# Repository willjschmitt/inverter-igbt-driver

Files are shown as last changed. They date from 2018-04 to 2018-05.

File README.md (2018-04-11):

# inverter-igbt-driver
IGBT driver for Electric Vehicle Inverter

This project is a work in progress to design a simple IGBT driver for use with the controls designed in https://github.com/willjschmitt/electric-vehicle-controller.

Board is designed in [KiCad](http://kicad-pcb.org/).

## Getting Started
```
git clone https://github.com/willjschmitt/inverter-igbt-driver
```

Install KiCad. Open up the KiCad project!

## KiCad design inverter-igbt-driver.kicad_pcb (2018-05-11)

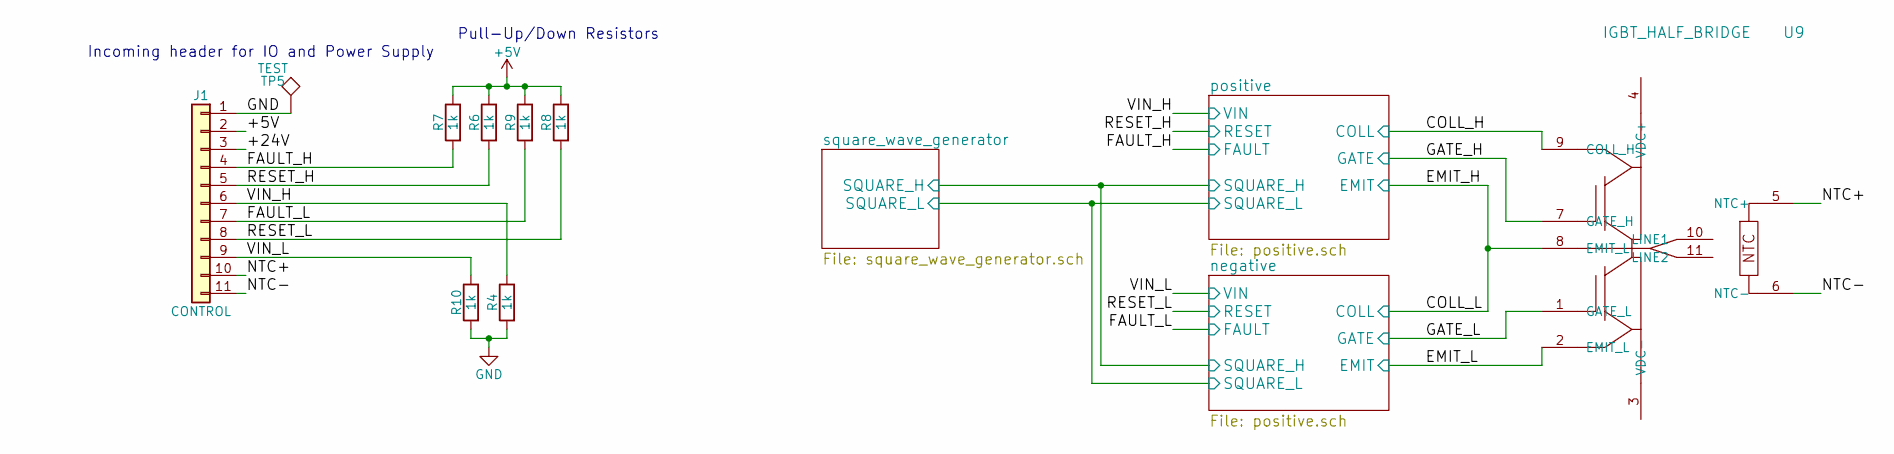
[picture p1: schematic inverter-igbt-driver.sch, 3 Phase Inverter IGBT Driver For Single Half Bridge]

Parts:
J1: CONTROL; Pin_Header_Straight_1x11_Pitch2.54mm
R4, R6, R7, R8, R9, R10: 1k; R_0402
TP5: TEST; TP RCT (0805)
U9: IGBT_HALF_BRIDGE; MG06600WB-BN4MM

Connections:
+5V: J1.2, R6.1, R7.1, R8.1, R9.1; also elsewhere on the board
+24V: J1.3; also elsewhere on the board
/COLL_H: U9.9 (COLL_H); also elsewhere on the board
/COLL_L: U9.8 (EMIT_L); also elsewhere on the board
/EMIT_L: U9.2 (EMIT_L); also elsewhere on the board
/FAULT_H: J1.4, R7.2; also elsewhere on the board
/FAULT_L: J1.7, R9.2; also elsewhere on the board
/GATE_H: U9.7 (GATE_H); also elsewhere on the board
/GATE_L: U9.1 (GATE_L); also elsewhere on the board
/NTC+: J1.10, U9.5 (NTC+)
/NTC-: J1.11, U9.6 (NTC-)
/RESET_H: J1.5, R6.2; also elsewhere on the board
/RESET_L: J1.8, R8.2; also elsewhere on the board
/VIN_H: J1.6, R4.1; also elsewhere on the board
/VIN_L: J1.9, R10.1; also elsewhere on the board
GND: J1.1, R4.2, R10.2, TP5.1; also elsewhere on the board

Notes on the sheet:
Incoming header for IO and Power Supply
Pull-Up/Down Resistors

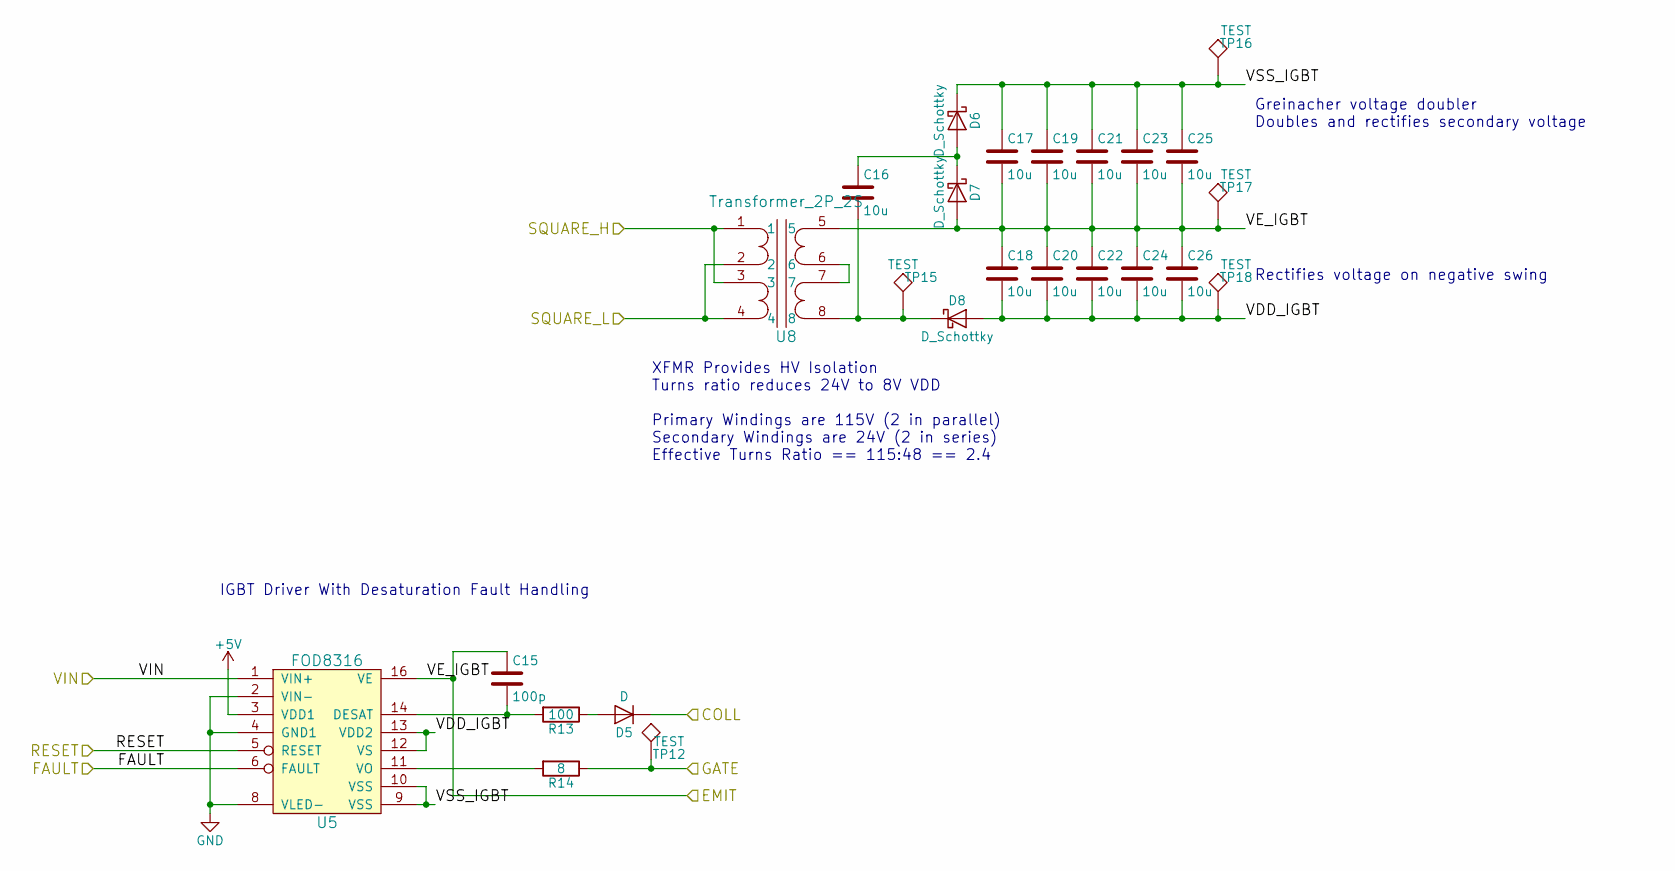
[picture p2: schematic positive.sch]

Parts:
C2, C3, C4, C5, C6, C7, C8, C9, C10, C11, C12: 10u; C_1206_HandSoldering
C13: 100p; C_1206_HandSoldering
D1, D2, D3: D_Schottky; D_SOD-123F
D4: D; DO-214AC
R2: 100; R_1206_HandSoldering
R3: 8; R_Axial_DIN0207_L6.3mm_D2.5mm_P7.62mm_Horizontal
TP4, TP6, TP7, TP8, TP9: TEST; TP RCT (0805)
U3: FOD8316; SOIC-16W_7.5x10.3mm_Pitch1.27mm
U6: Transformer_2P_2S; FS48-050-C2

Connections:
+5V: U3.3 (VDD1); also elsewhere on the board
/COLL_H: D4.1 (K); also elsewhere on the board
/COLL_L: C3.2, C4.1, C5.2, C6.1, C7.2, C8.1, C9.2, C10.1, C11.2, C12.1, C13.1, D2.2 (A), TP8.1, U3.16 (VE), U6.5; also elsewhere on the board
/FAULT_H: U3.6 (FAULT); also elsewhere on the board
/GATE_H: R3.1, TP4.1; also elsewhere on the board
/RESET_H: U3.5 (RESET); also elsewhere on the board
/VIN_H: U3.1 (VIN+); also elsewhere on the board
/negative/SQUARE_H: U6.1, U6.3; also elsewhere on the board
/negative/SQUARE_L: U6.2, U6.4; also elsewhere on the board
/positive/VDD_IGBT: C4.2, C6.2, C8.2, C10.2, C12.2, D3.2 (A), TP9.1, U3.12 (VS), U3.13 (VDD2)
/positive/VSS_IGBT: C3.1, C5.1, C7.1, C9.1, C11.1, D1.1 (K), TP7.1, U3.9 (VSS), U3.10 (VSS)
GND: U3.2 (VIN-), U3.4 (GND1), U3.8 (VLED-); also elsewhere on the board
unnamed: C2.1, D1.2 (A), D2.1 (K)
unnamed: C2.2, D3.1 (K), TP6.1, U6.8
unnamed: C13.2, R2.2, U3.14 (DESAT)
unnamed: D4.2 (A), R2.1
unnamed: R3.2, U3.11 (VO)
unnamed: U6.6, U6.7

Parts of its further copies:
C15: 100p; C_1206_HandSoldering
C16, C17, C18, C19, C20, C21, C22, C23, C24, C25, C26: 10u; C_1206_HandSoldering
D5: D; DO-214AC
D6, D7, D8: D_Schottky; D_SOD-123F
R13: 100; R_1206_HandSoldering
R14: 8; R_Axial_DIN0207_L6.3mm_D2.5mm_P7.62mm_Horizontal
TP12, TP15, TP16, TP17, TP18: TEST; TP RCT (0805)
U5: FOD8316; SOIC-16W_7.5x10.3mm_Pitch1.27mm
U8: Transformer_2P_2S; FS48-050-C2

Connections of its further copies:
+5V: U5.3 (VDD1); also elsewhere on the board
/COLL_L: D5.1 (K); also elsewhere on the board
/EMIT_L: C15.1, C17.2, C18.1, C19.2, C20.1, C21.2, C22.1, C23.2, C24.1, C25.2, C26.1, D7.2 (A), TP17.1, U5.16 (VE), U8.5; also elsewhere on the board
/FAULT_L: U5.6 (FAULT); also elsewhere on the board
/GATE_L: R14.1, TP12.1; also elsewhere on the board
/RESET_L: U5.5 (RESET); also elsewhere on the board
/VIN_L: U5.1 (VIN+); also elsewhere on the board
/negative/SQUARE_H: U8.1, U8.3; also elsewhere on the board
/negative/SQUARE_L: U8.2, U8.4; also elsewhere on the board
/negative/VDD_IGBT: C18.2, C20.2, C22.2, C24.2, C26.2, D8.2 (A), TP18.1, U5.12 (VS), U5.13 (VDD2)
/negative/VSS_IGBT: C17.1, C19.1, C21.1, C23.1, C25.1, D6.1 (K), TP16.1, U5.9 (VSS), U5.10 (VSS)
GND: U5.2 (VIN-), U5.4 (GND1), U5.8 (VLED-); also elsewhere on the board
unnamed: C15.2, R13.2, U5.14 (DESAT)
unnamed: C16.1, D6.2 (A), D7.1 (K)
unnamed: C16.2, D8.1 (K), TP15.1, U8.8
unnamed: D5.2 (A), R13.1
unnamed: R14.2, U5.11 (VO)
unnamed: U8.6, U8.7

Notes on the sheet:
XFMR Provides HV Isolation Turns ratio reduces 24V to 8V VDD Primary Windings are 115V (2 in parallel) Secondary Windings are 24V (2 in series) Effective Turns Ratio == 115:48 == 2.4
Greinacher voltage doubler Doubles and rectifies secondary voltage
Rectifies voltage on negative swing
IGBT Driver With Desaturation Fault Handling

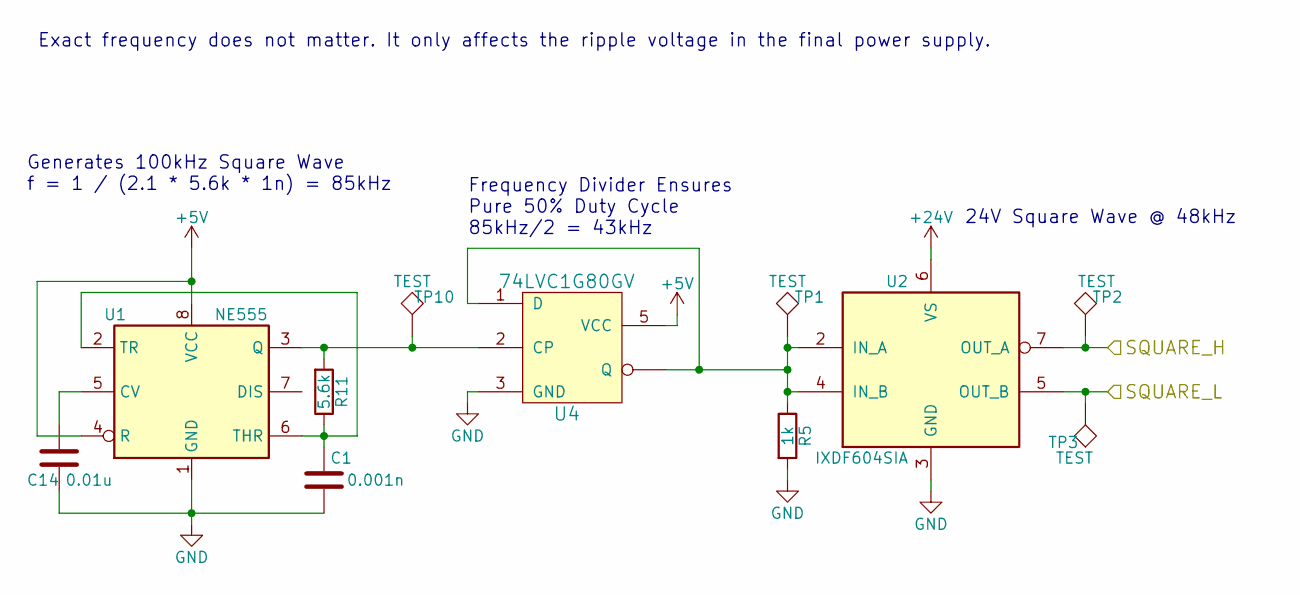
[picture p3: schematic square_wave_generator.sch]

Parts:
C1: 0.001n; C_0603_HandSoldering
C14: 0.01u; C_0603_HandSoldering
R5: 1k; R_0402
R11: 5.6k; R_0603_HandSoldering
TP1, TP2, TP3, TP10: TEST; TP RCT (0805)
U1: NE555; SOIC-8_3.9x4.9mm_Pitch1.27mm
U2: IXDF604SIA; SOIC-8_3.9x4.9mm_Pitch1.27mm
U4: 74LVC1G80GV; SOT-353_SC-70-5_Handsoldering

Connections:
+5V: U1.4 (R), U1.8 (VCC), U4.5 (VCC); also elsewhere on the board
+24V: U2.6 (VS); also elsewhere on the board
/negative/SQUARE_H: TP2.1, U2.7 (OUT_A); also elsewhere on the board
/negative/SQUARE_L: TP3.1, U2.5 (OUT_B); also elsewhere on the board
GND: C1.2, C14.2, R5.2, U1.1 (GND), U2.3 (GND), U4.3 (GND); also elsewhere on the board
unnamed: C1.1, R11.1, U1.2 (TR), U1.6 (THR)
unnamed: C14.1, U1.5 (CV)
unnamed: R5.1, TP1.1, U2.2 (IN_A), U2.4 (IN_B), U4.1 (D), U4.~ (Q)
unnamed: R11.2, TP10.1, U1.3 (Q), U4.2 (CP)

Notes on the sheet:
Generates 100kHz Square Wave f = 1 / (2.1 * 5.6k * 1n) = 85kHz
24V Square Wave @ 48kHz
Frequency Divider Ensures Pure 50% Duty Cycle 85kHz/2 = 43kHz
Exact frequency does not matter. It only affects the ripple voltage in the final power supply.

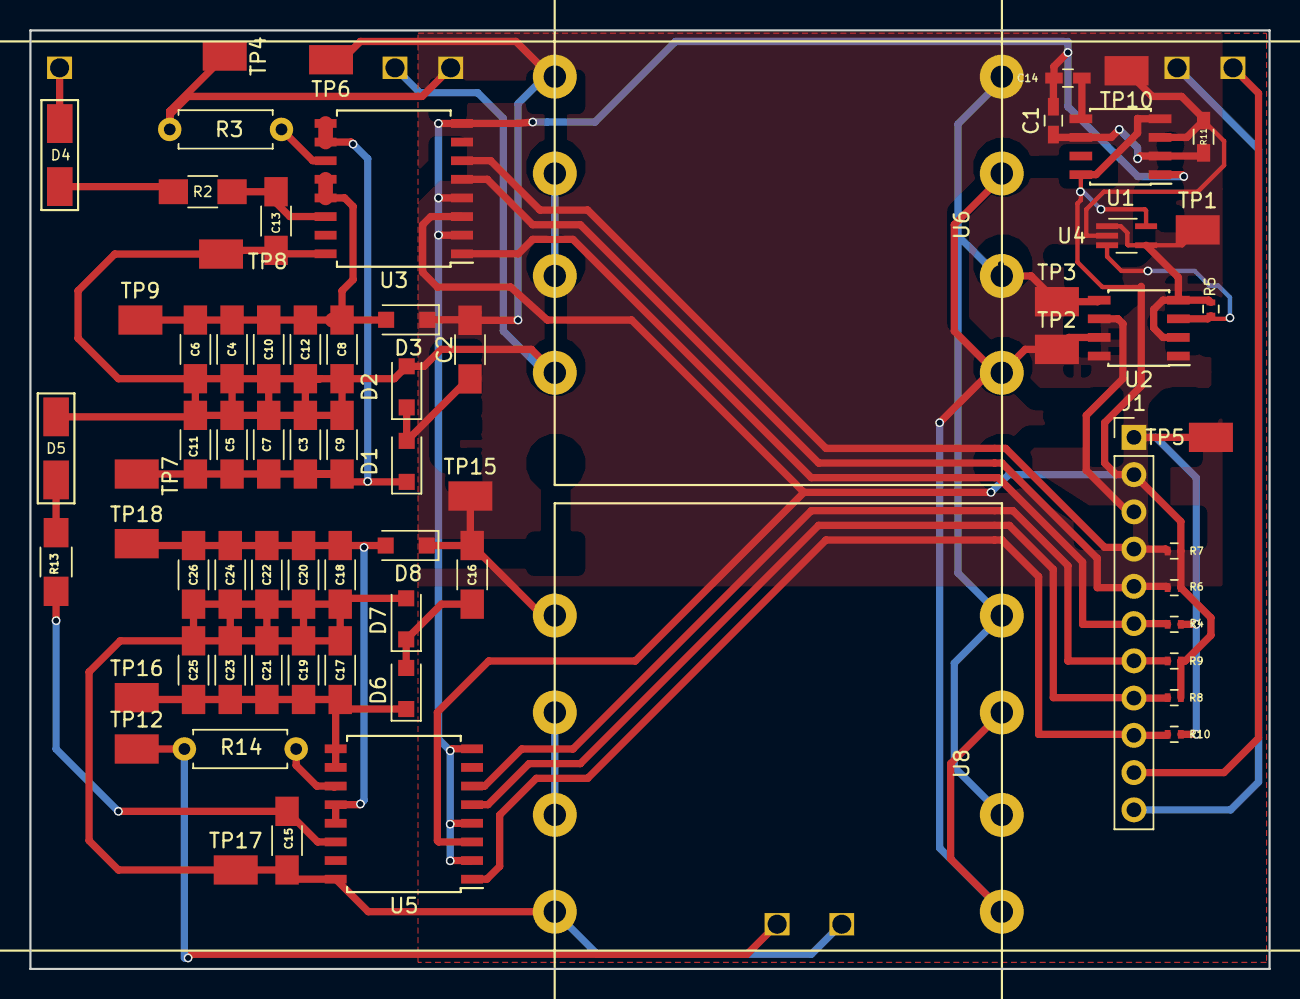
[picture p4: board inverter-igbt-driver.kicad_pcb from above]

Board: 2 copper layers, 84.5 x 64.0 mm, 70 parts (0 on the bottom side), 38 nets.

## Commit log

2018-04-10 First attempt at a complete IGBT driver.
    [inverter-igbt-driver.kicad_pcb, inverter-igbt-driver.sch]
2018-04-10 Adds pull-down resistors for logic nets.
    [inverter-igbt-driver.kicad_pcb, inverter-igbt-driver.sch]
2018-04-10 Add GND test point.
    [inverter-igbt-driver.kicad_pcb, inverter-igbt-driver.sch]
2018-04-10 Fix emitter connection.
    [inverter-igbt-driver.kicad_pcb]
2018-04-11 Switching pull-down to pull-up resistors for fault/reset.
    [inverter-igbt-driver.kicad_pcb, inverter-igbt-driver.sch]
2018-04-20 Refactor into schematic.
    [inverter-igbt-driver.kicad_pcb, inverter-igbt-driver.sch, positive.sch]
2018-04-20 Fix test point connection.
    [inverter-igbt-driver.kicad_pcb]
2018-04-21 Including both igbt drivers on one board.
    WIP
    [inverter-igbt-driver.kicad_pcb, inverter-igbt-driver.sch, positive.sch]
2018-04-21 Add _H suffix to hot leg.
    [inverter-igbt-driver.kicad_pcb, inverter-igbt-driver.sch]
2018-04-21 Move square wave generator to single module.
    [inverter-igbt-driver.kicad_pcb, inverter-igbt-driver.sch, positive.sch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]
2018-04-21 Fixing layout
    [inverter-igbt-driver.kicad_pcb, inverter-igbt-driver.sch]
2018-04-22 Completed layout with one connector.
    [inverter-igbt-driver.kicad_pcb, inverter-igbt-driver.sch, positive.sch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]
2018-04-29 Wire adjustments
    [inverter-igbt-driver.sch]
2018-05-05 Changed 555 timer configuration.
    555 timer was not behaving correctly. Added resistor to out for timing and increased resistor to 5V to mostly open circuit (in steady state).
    Added extra coupling capacitor for control voltage.
    [inverter-igbt-driver.kicad_pcb, positive.sch, square_wave_generator.sch]
2018-05-05 Adds NTC to connector.
    Completes 555 rewire.
    Rewires IGBT signals to layout more simply.
    [inverter-igbt-driver.kicad_pcb, inverter-igbt-driver.sch, positive.sch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]
2018-05-05 Fix hole size for avoiding slotting in OshPark drilling.
    [inverter-igbt-driver.kicad_pcb]
2018-05-05 Cleaning up layout of main connector.
    [inverter-igbt-driver.sch]
2018-05-08 Changing 555 timer again to remove pullup resistor and discharge.
    [inverter-igbt-driver.kicad_pcb, square_wave_generator.sch]
2018-05-08 Adding d-flop to achieve 50% duty cycle
    555 timer config cannot guarantee 50% duty cycle, but a frequency divider can.
    [inverter-igbt-driver.kicad_pcb, inverter-igbt-driver.sch, square_wave_generator.sch]
2018-05-11 Adjust resistor value and cap values for pulse generator
    [inverter-igbt-driver.sch, positive.sch, square_wave_generator.sch]
2018-05-11 Update values.
    [inverter-igbt-driver.kicad_pcb]
